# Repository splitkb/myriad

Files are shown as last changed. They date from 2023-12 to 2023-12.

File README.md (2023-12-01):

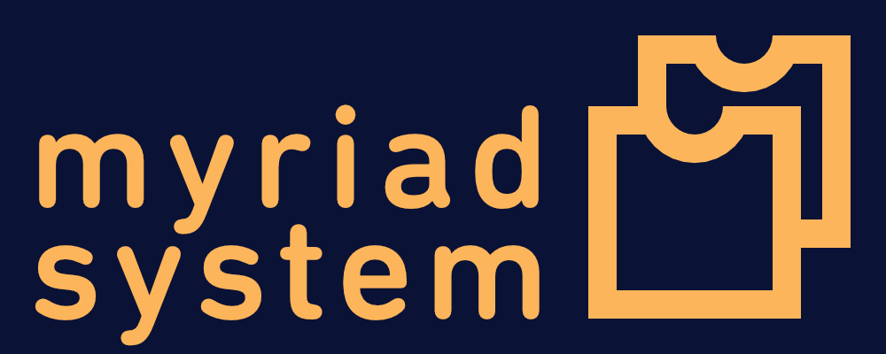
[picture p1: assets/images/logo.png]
Myriad logo


# Myriad

This repository stores the public documentation for the [Myriad System](https://myriad.splitkb.com/). Did you see any mistakes? Feel free to submit a pull request!

## Symbols & footprints
You can find KiCad symbols and footprints [here](assets/kicad/).

## Example projects
You can find some example projects [here](assets/example_projects/).

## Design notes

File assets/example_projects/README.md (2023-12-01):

# Myriad Example projects
Having trouble getting started with your Myriad project? Why not [take a look](https://github.com/splitkb/myriad/archive/refs/heads/main.zip) at these example projects to get an idea of what the end result should look like.

_(Having trouble finding this directory in the ZIP? It's under `assets/kicad`!)_

## protoboard_??x??
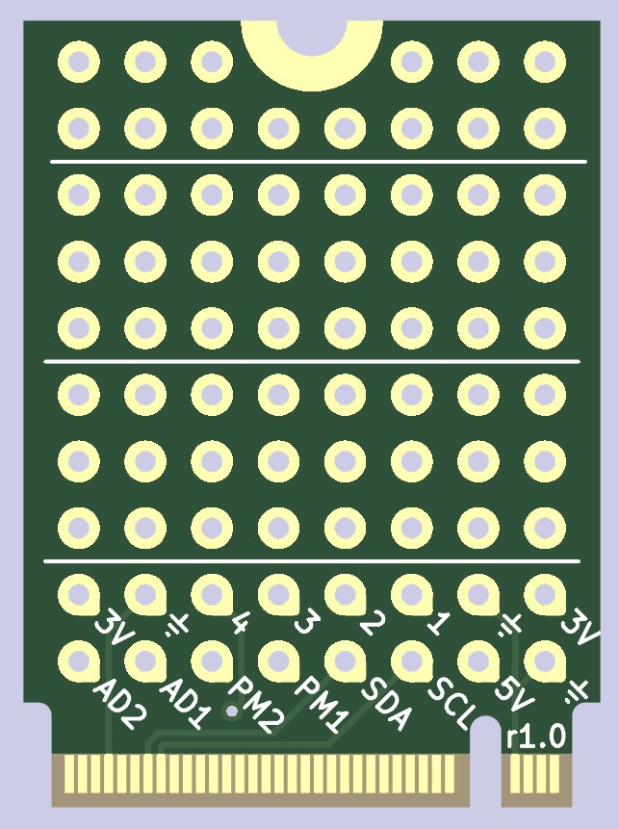
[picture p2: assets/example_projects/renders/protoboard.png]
Proto board


Simple prototyping board. Exposes basic GPIO functionality on the bottom two rows, while providing 3-long strips on the rest of the card. You can use this to build your own simple modules, without having to get a PCB manufactured.

## breakout_22x30
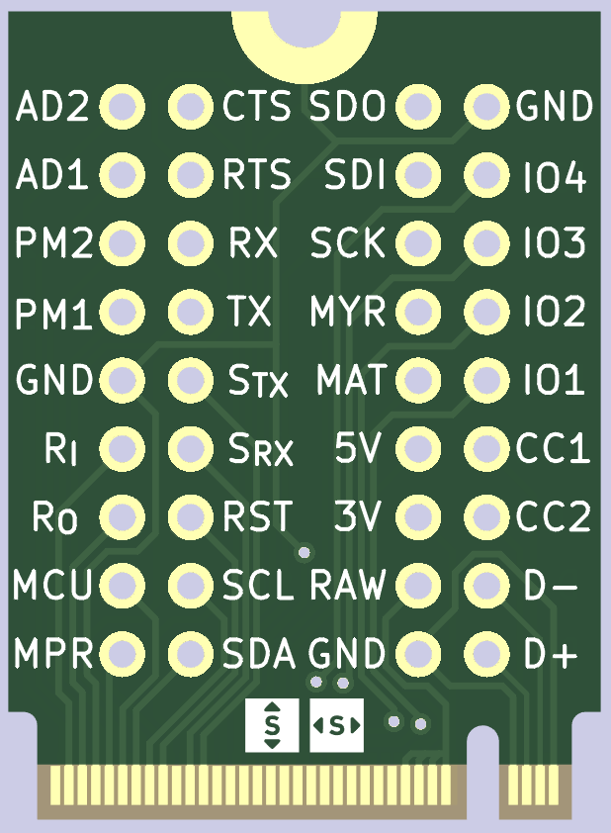
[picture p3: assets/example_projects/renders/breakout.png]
Breakout board


Breakout board. Exposes all currently-available Myriad pins, making it ideal if you want to try connecting external hardware to it.

## Licensing

These files are available for **non-commercial use only**. See [https://myriad.splitkb.com/specification/terms_of_use.html](https://myriad.splitkb.com/specification/terms_of_use.html) for more information.

## More information

Are you looking for the specification, or just want to know more about the Myriad system in general? Visit [https://myriad.splitkb.com/](https://myriad.splitkb.com/)!

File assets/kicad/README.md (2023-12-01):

# Symbols & Footprints

The Myriad system uses a relatively complicated form factor. Especially the edge connector isn't a lot of fun to model.

Luckily, you don't have to! If you're using KiCad, we have created all the required files for you. Just [download this repository](https://github.com/splitkb/myriad/archive/refs/heads/main.zip), add `footprints/` as a footprint library and `symbols/myriad.kycad_sym` as a symbol library, and you're good to go.

_(Having trouble finding this directory in the ZIP? It's under `assets/kicad`!)_

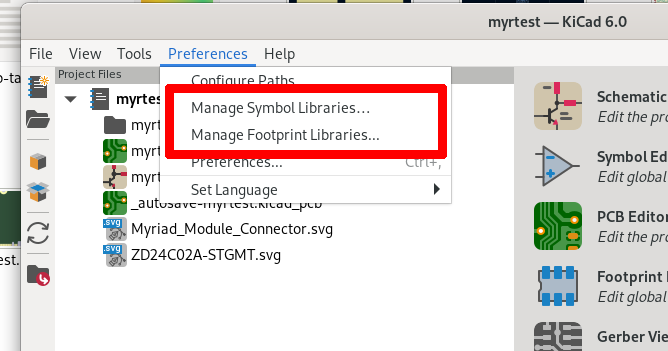
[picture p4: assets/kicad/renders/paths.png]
Kicad paths


## Symbols
### Myriad_Module_Connector
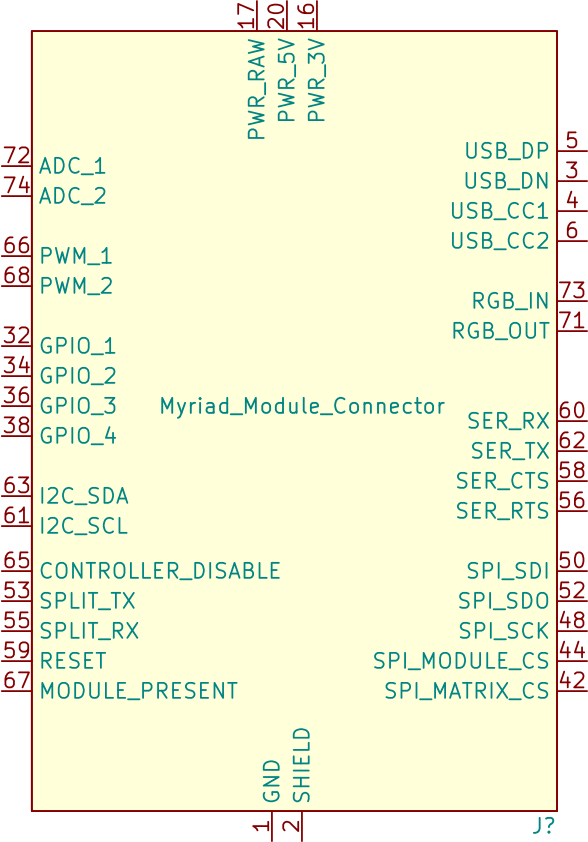
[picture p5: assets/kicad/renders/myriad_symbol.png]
Myriad symbol


This is probably the most important symbol for you: the Myriad module itself. All connections are grouped by purpose.  To figure out how they are supposed to be used, see the [Electrical Specification](https://myriad.splitkb.com/specification/electrical.html) and [Pinout](https://myriad.splitkb.com/specification/pinout.html) for more information. 

They can be paired with the [Myriad_Module_??x??mm](#myriad_module_xmm) and [Myriad_Module_Edge](#myriad_module_edge) footprints.

### Myriad_Keyboard_Connector
It's essentially the same as Myriad_Module_connector, but from the keyboard side. We just flipped the inputs and outputs.

You can use it together with the [Myriad_Socket](#myriad_socket) footprint.

### ZD24C02A-STGMT
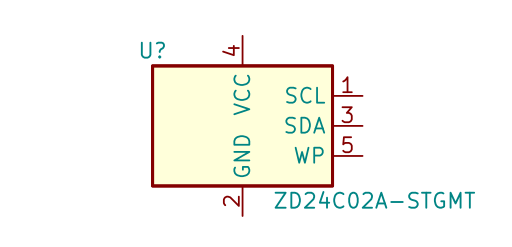
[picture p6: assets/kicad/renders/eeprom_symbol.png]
Zetta symbol


The [Zetta ZD24CxxA](https://www.lcsc.com/product-detail/EEPROM_Zetta-ZD24C08A-STGMT_C2896640.html) is a cheap generic I2C EEPROM which can be used for [card identification](https://myriad.splitkb.com/specification/card_identification/). 

It uses the regular KiCad-provided SOT-23-5 footprint.

Don't feel forced to use this *specific* EEPROM chip - we chose this one for our products because it is cheap and widely available. Did you find a different one? Make sure to compare the [datasheets](https://datasheet.lcsc.com/lcsc/2109141830_Zetta-ZD24C08A-STGMT_C2896640.pdf) for compatibility.

## Footprints
### Myriad_Module_??x??mm
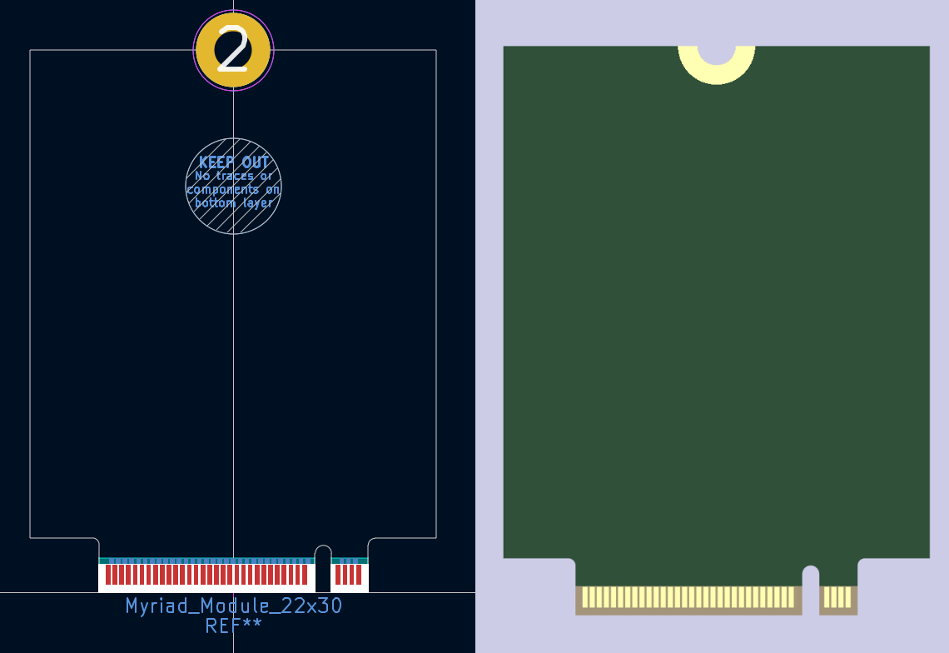
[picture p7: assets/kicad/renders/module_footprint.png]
Module footprint


Premade module footprints including the connector and relevant edge cuts are available for the [common module dimensions](https://myriad.splitkb.com/specification/physical.html). They use the [Myriad_Module_Connector](#myriad_module_connector) symbol.

### Myriad_Module_Edge
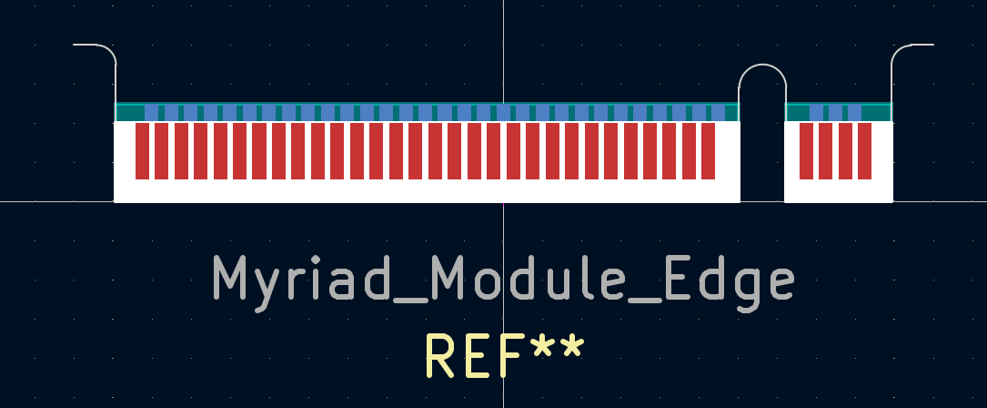
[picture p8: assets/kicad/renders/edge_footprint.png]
Edge footprint


If you're making a module which does not follow the standard sizing edge cuts, we also provide a separate footprint for just the edge connector. This also uses the [Myriad_Module_Connector](#myriad_module_connector) symbol.

Don't forget to add the plated through-hole for screwing it down, and keep the [keepout area](https://myriad.splitkb.com/specification/physical.html#keepout-areas) in mind!

### Myriad_Graphic_{Length/Width}-{S/M/L}
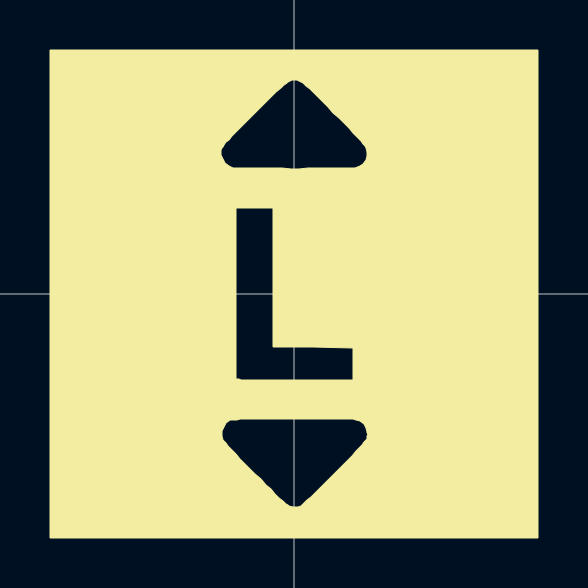
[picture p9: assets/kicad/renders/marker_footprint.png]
Size indicator footprint


These markers can be placed on the module to indicate the standard size they are using. 

### Myriad_Socket
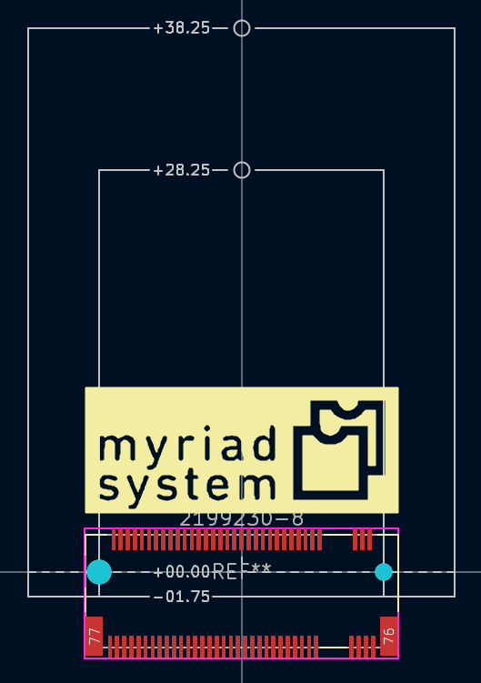
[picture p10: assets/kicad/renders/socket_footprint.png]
Socket footprint


If you're designing a Myriad-compatible keyboard, you can use this footprint to easily get the right dimensions. It is built around the [Myriad_Keyboard_Connector](#myriad_keyboard_connector) footprint and uses the [TE Connectivity 2199230-8](https://octopart.com/2199230-8-te+connectivity-46436158) connector.

It comes with a Myriad logo, outlines of the Small & Medium cards on the `User.Drawings` layer, and offset markers for the `Myriad_Socket_Standoff` footprints.

### Myriad_Socket_Standoff_??mm

Used in combination with the `Myriad_Socket` footprint's `2199230-8`, they mount [Wurth Elektronic 9774025151R](https://octopart.com/9774025151r-wurth+elektronik-59774856) SMD screw standoffs.

Place only the 30mm one for Small cards, and use both 30mm and 40mm for Medium cards and above. If the marker on the `User.Drawings` layer matches up with the +00 line of the Myriad_Socket footprint, they are in the right spot.

## Licensing

See [https://myriad.splitkb.com/specification/terms_of_use.html](https://myriad.splitkb.com/specification/terms_of_use.html).

## More information

Are you looking for the specification, or just want to know more about the Myriad system in general? Visit [https://myriad.splitkb.com/](https://myriad.splitkb.com/)!

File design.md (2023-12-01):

---
layout: default
title: Design your own
nav_order: 4
---

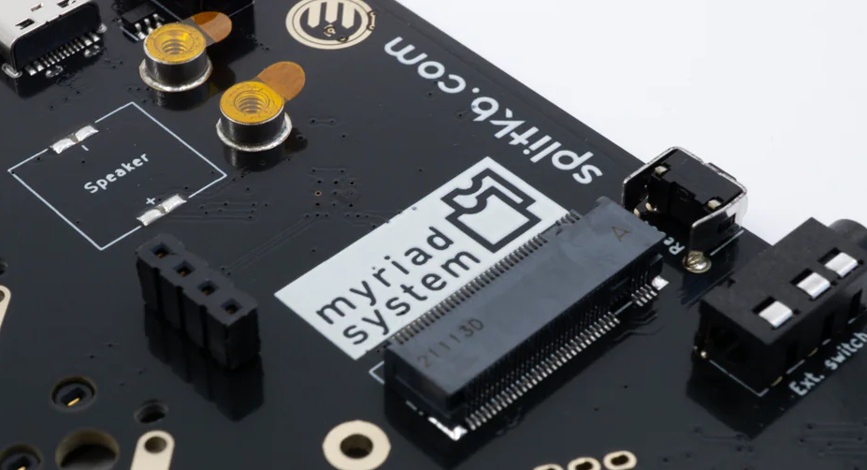
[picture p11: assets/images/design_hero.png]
A Myriad connector


# Specifications
The Myriad system is exhaustively described in [the specifications](specification/).

# Symbols & Footprints
In order to save you some time, we have already created the necessary KiCad footprints and symbols for you. You can find them [here](https://github.com/splitkb/myriad/tree/main/assets/kicad).

# Example projects
Prefer looking at ready-made cards to get a feel of it? Why not take a look at [these](https://github.com/splitkb/myriad/tree/main/assets/example_projects)?

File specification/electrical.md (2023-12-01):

---
layout: default
title: Electrical Specifications
parent: Specification
nav_order: 2
---

# Electrical Specification
Unless stated otherwise, all IO pins use 3.3V.

IO pins are driven from a microcontroller, so expect them to sink/source about 10mA. You can power a LED from them, but don't expect them to drive a servo.

# Power
The keyboard provides three potential power sources to the card.

## 3V3
This is the main supply for digital logic. It is always available. The keyboard has to convert the 5V provided from USB into 3V3, so anything drawing very large amounts of current should use the 5V rail instead.

Keyboards are expected to supply about 500mA on the 3V3 rail.

## 5V
Used to supply power-hungry components, like RGB LEDs. It is available on both sides of a split keyboard.

The 5V supply must be protected by an overcurrent fuse on the keyboard. As with any USB device, expect it to supply about 500mA.

{: .note }
Controller modules are not required to supply 5V to the keyboard: the keyboard is required to operate with only 3V3.

## Raw
Direct power from the USB connector, used for things like battery charging.

A module can **passively** measure the voltage on the two [CC pins](pinout.html#usb) to determine roughly how much power can be drawn. The highest voltage determines the maximum current allowed:

|Voltage  |Allowed current|
|---|---|
|< 0.2V |None, USB disconnected |
|0.2V - 0.66V |500 mA |
|0.66V - 1.23V|1500 mA |
|> 1.23V |2000 mA |

A module may **never** draw more than 2000 mA, as that is the absolute limit of the connector.

{: .warning }
USB PD communication is **explicitly forbidden**. The module may **only** measure the voltage present on the CC pins.

{: .note }
On split keyboards, raw power is only available on the primary half.

# Ground
Ground pins have been distributed along the connector. Connect ground pins close to high-speed connections for better signal integrity.

All ground pins are connected on the keyboard, feel free to leave some disconnected when not needed.

# Reserved pins
For compatibility with future revisions, all reserved pins **must** be left floating.

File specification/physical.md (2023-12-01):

---
layout: default
title: Physical Dimensions
parent: Specification
nav_order: 1
---
# Physical Dimensions

Myriad cards use the M.2 form factor, also known as "NGFF". It is commonly used by NVMe SSDs and Wifi cards. This means that the [M.2 specification](/assets/pdf/m2_spec.pdf) serves as the basis for the Myriad specification.

This page describes the physical dimensions required to create a Myriad-compatible card. You can also use one of our [footprints](/design.html#resources) if you want to save yourself some trouble.

{: .warning }
Make sure you order your cards with a thickness of 0.80mm!

## Keying
Myriad cards, like all other M.2 cards, have a physical "notch" preventing the insertion of incompatible cards. Myriad cards use **Key A**. This means pins 8-15 are missing. Pins 24-31 (Key E) are [kept reserved](electrical.html#reserved-pins) for potential future use.

## Card edge
In order to allow insertion, the card must be 0.80mm (± 0.08mm) thick. ENIG finish is strongly recommended for durability. Contrary to the M.2 specification, a card edge bevel is not required.

For card edge pads and cutout dimensions, please see Figure 16 through 18 of the [M.2 specification](/assets/pdf/m2_spec.pdf) (pages 39-41). We recommend using our pre-existing [footprints](/design.html#resources) to avoid having to manually copy this.

## Card dimensions
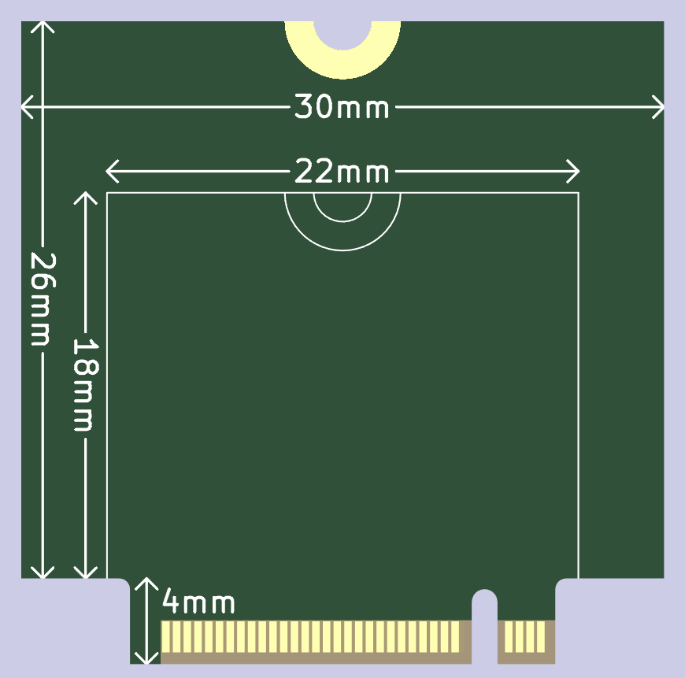
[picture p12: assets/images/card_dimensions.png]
Card dimensions


We define a set of standard card sizes to make it easier to determine whether a card will fit a specific keyboard.

The following sizes are defined:

| *Size codes* | **22mm wide** | **30mm wide** | **> 30mm wide** |
| **22mm tall** | SS | SM | SL |
| **30mm tall** | MS | MM | ML |
| **> 30mm tall** | LS | LM | LL |

Cards which are Small or Medium in either width or height will always fit into a keyboard matching that size. Cards which have one or more Large dimensions are *not* guaranteed to fit - the card maker should publish exact dimensions and compatibility with the most common keyboards.

If physically possible, the size code should be marked LINK on the card itself.

{: .note }
Card height includes the 4mm needed for the connector.

## Standoff
The card is secured using a standoff and regular M2.5 screw. If the keyboard supports cards of length S (22mm) or larger, a standoff will be present at 22mm. If the keyboard supports cards of length M (30mm) or larger, a second standoff will be present at 30mm.

The card must have a circular cutout at either y=22mm or y=30mm with a diameter of 2.7mm (radius 1.35mm), surrounded by a plated pad with a diameter of 5.4mm (radius 2.7mm). On most cards, this will result in a half-circle due to the card's length.

## Keepout areas
In order to avoid interfering with the socket, do not place any components:
- Within 4.0mm of the connector card edge on the frontside.
- Within 5.2mm of the connector card edge on the backside.

Within a 3.5mm radius of (x=0mm, y=30mm) on the backside, do not place any components n order to avoid interfering with the 30mm standoff. Placing signal or power traces in this area is **strongly** discouraged, but a ground plane is fine.

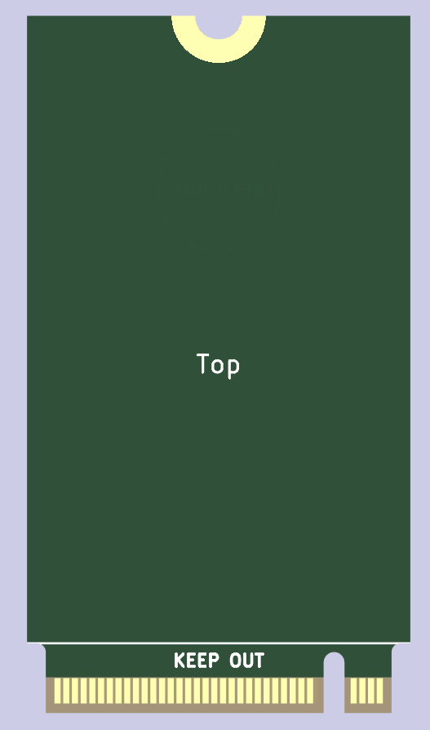
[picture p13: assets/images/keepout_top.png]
Keepout areas front

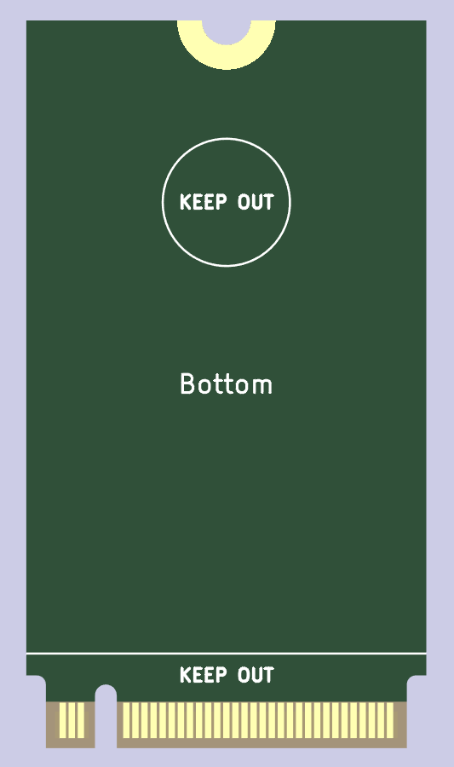
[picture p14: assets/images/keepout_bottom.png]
Keepout areas back


## Vertical spacing
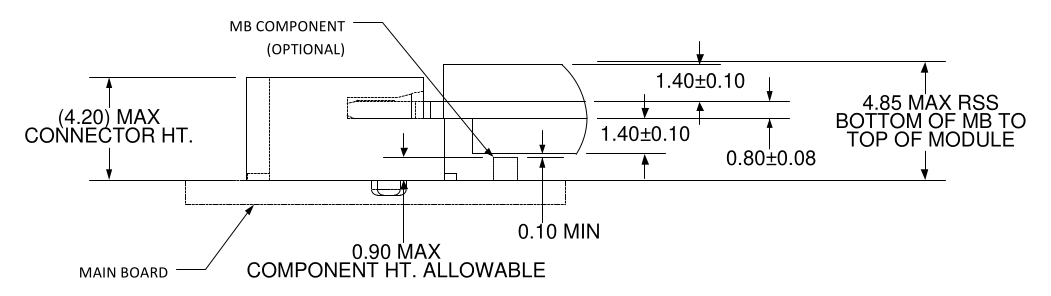
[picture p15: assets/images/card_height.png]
Card height


Components on the **bottom** of the cards must be at most **1.40mm** tall, leaving 0.90mm for components placed on the keyboard. Component height on the **top** is unrestricted, provided they remain within the card boundaries.

{: .note }
Keyboards may use connectors shorter than 4.20mm - but that makes finding standoffs a lot trickier.

## Mounting Hardware
If you are designing your own keyboard, we recommend the TE Connectivity [2199230-8](https://octopart.com/2199230-8-te+connectivity-46436158) ([datasheet](/assets/pdf/socket_datasheet.pdf)) connector  and Wurth Elektronik [9774025151R](https://octopart.com/9774025151r-wurth+elektronik-59774856) ([datasheet](/assets/pdf/standoff_datasheet.pdf)) standoffs, but any compatible ones will do.

Footprints are provided in our [repository](/design.html#resources).

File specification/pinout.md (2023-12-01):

---
layout: default
title: Pinout
parent: Specification
nav_order: 3
---

# Myriad Pinout
This document serves as a reference when creating Myriad cards. You don't need to make your own symbols - we already did that [for you](design.html#resources)

- *Odd pins are on the top, even pins are on the bottom*
- *Pins marked with a 🚧 may only be used by [controller cards](#controller-cards)*
- *Unless explicitly stated otherwise, all IO pins use 3.3V.*

|\#|Group|Name|Description|
|---|---|-----|----|---|
|01|[Power](electrical.html#power)|GND|Ground|
|02|[Power](electrical.html#power)|Shield|Case shield|
|03|[USB](#usb)|D- [🚧](#controller-cards)|USB data|
|04|[USB](#usb)|CC 1|USB current sense|
|05|[USB](#usb)|D+ [🚧](#controller-cards)|USB data|
|06|[USB](#usb)|CC 2|USB current sense|
|07|[Power](electrical.html#power)|GND|Ground|
|08-15|*(Unused)*|*Key A*|Board cutout|
|16|[Power](electrical.html#power)|3V3||
|17|[Power](electrical.html#power)|Raw||
|18|[Power](electrical.html#power)|3V3||
|19|[Power](electrical.html#power)|Raw||
|20|[Power](electrical.html#power)|5V||
|21|[Power](electrical.html#power)|Raw||
|22|[Power](electrical.html#power)|5V||
|23|[Power](electrical.html#power)|Raw||
|24-31|*(Unused)*|*(Reserved)*|[Leave disconnected](electrical.html#reserved-pins)|
|32|[GPIO](#gpio)|GPIO 1|General-purpose IO|
|33|*(Unused)*|*(Reserved)*|[Leave disconnected](electrical.html#reserved-pins)|
|34|[GPIO](#gpio)|GPIO 2|General-purpose IO|
|35|*(Unused)*|*(Reserved)*|[Leave disconnected](electrical.html#reserved-pins)|
|36|[GPIO](#gpio)|GPIO 3|General-purpose IO|
|37|*(Unused)*|*(Reserved)*|[Leave disconnected](electrical.html#reserved-pins)|
|38|[GPIO](#gpio)|GPIO 4|General-purpose IO|
|39|*(Unused)*|*(Reserved)*|[Leave disconnected](electrical.html#reserved-pins)|
|40|[Power](electrical.html#power)|GND|Ground|
|41|*(Unused)*|*(Reserved)*|[Leave disconnected](electrical.html#reserved-pins)|
|42|[SPI](#spi)|[Matrix CS](#matrix-data) [🚧](#controller-cards)|Chip Select, keyboard matrix|
|43|*(Unused)*|*(Reserved)*|[Leave disconnected](electrical.html#reserved-pins)|
|44|[SPI](#spi)|Myriad CS|Chip Select, Myriad module|
|45|*(Unused)*|*(Reserved)*|[Leave disconnected](electrical.html#reserved-pins)|
|46|[Power](electrical.html#power)|GND|Ground|
|47|*(Unused)*|*(Reserved)*|[Leave disconnected](electrical.html#reserved-pins)|
|48|[SPI](#spi)|SCK|Clock|
|49|*(Unused)*|*(Reserved)*|[Leave disconnected](electrical.html#reserved-pins)|
|50|[SPI](#spi)|SDI|Data, Module to Keyboard|
|51|*(Unused)*|*(Reserved)*|[Leave disconnected](electrical.html#reserved-pins)|
|52|[SPI](#spi)|SDO|Data, Keyboard to Module|
|53|Misc|[Split Comm.](#split-communication) TX [🚧](#controller-cards)|Serial link between halves, transmit|
|54|[Power](electrical.html#power)|GND|Ground|
|55|Misc|[Split Comm.](#split-communication) RX [🚧](#controller-cards)|Serial link between halves, receive|
|56|[Serial](#serial)|RTS|Request-To-Send, Keyboard to Module|
|57|[Power](electrical.html#power)|GND|Ground|
|58|[Serial](#serial)|CTS|Clear-To-Send, Module to Keyboard|
|59|Misc|[Reset](#reset)|Reset keyboard & module|
|60|[Serial](#serial)|RX|Data, Module to Keyboard|
|61|[I2C](#i2c)|SCL|Clock|
|62|[Serial](#serial)|TX|Data, Keyboard to Module|
|63|[I2C](#i2c)|SDA|Data|
|64|[Power](electrical.html#power)|GND|Ground|
|65|Misc|[Controller Disable](#controller-disable) [🚧](#controller-cards)|Keyboard controller override|
|66|[PWM](#pwm)|PWM 1|Pulse-width modulation|
|67|Misc|[Module Present](#module-presence)|Myriad module inserted|
|68|[PWM](#pwm)|PWM 2|Pulse-width modulation|
|69|[Power](electrical.html#power)|GND|Ground|
|70|[Power](electrical.html#power)|GND|Ground|
|71|RGB|[RGB Out](#rgb)|RGB data, Keyboard to Module|
|72|[ADC](#adc)|ADC 1|Analog input|
|73|RGB|[RGB In](#rgb-1) [🚧](#controller-cards)|RGB data, Module to Keyboard|
|74|[ADC](#adc)|ADC 2|Analog input|
|75|*(Unused)*|*(Reserved)*|[Leave disconnected](electrical.html#reserved-pins)|

# Basic IO

### Reset
The Myriad module and keyboard share an active-low Reset signal. This can be used both to have a press of the on-keyboard reset button reset hardware placed on the Myriad card, or to have an additional reset button for the keyboard on the Myriad card. The keyboard will provide a pull-up.

### Module Presence
All [identifiable](card_identification/) Myriad cards **must** short Module Presence to Ground to indicate that a card has been inserted. Leave it floating for cards which cannot be automatically identified.

{: .note }
Automatic identification doesn't make sense for all cards. For example, a breakout board does not have fixed functionality, so it should not have an EEPROM chip and the Module Presence pin should be left floating.

### Signals

|\#| Pin |
|--|-----|
|59| Reset |
|67| Module presence |

## GPIO
GPIO pins can be used for general low-speed IO such as reading a push button or controlling a LED. They can be used for both input and output.

GPIO pins have support for internal pullup resistors, but internal pulldown resistors are not guaranteed. If you need pulldown resistors, you have to add them yourself.

### Signals

|\#| Pin |
|--|-----|
|32| GPIO 1 |
|34| GPIO 2 |
|36| GPIO 3 |
|38| GPIO 4 |

## PWM
The two PWM pins can be used to output analog-like signals, such as lighting with varying brightness or a speaker.

They can double as additional GPIO outputs if needed.

### Signals

|\#| Pin |
|--|-----|
|66| PWM 1 |
|68| PWM 2 |

## ADC
The two ADC pins can be used to read analog signals, for example from potentiometers or joysticks.

They can double as additional GPIO inputs if needed.

### Signals

|\#| Pin |
|--|-----|
|72| ADC 1 |
|74| ADC 2 |

## RGB
The Myriad module may have one or more WS2812B-compatible RGB LEDs. It is chained through similar LEDs on the keyboard itself, if any.

{: .warning }
Because the RGB data is provided by the previous LED in the chain, this is a **5V signal**.

### Signals

|\#| Pin |
|--|-----|
|71| RGB Out |

# Advanced IO
## SPI
[SPI](https://en.wikipedia.org/wiki/Serial_Peripheral_Interface) is the primary high-speed data bus for Myriad. It can transfer data at a rate of over 1Mbps, which should be sufficient for even the most demanding accessories.

### Implementation Notes

- **The module may only interact with SDI / SDO when CS is LOW**. When CS is HIGH, all signals coming from the keyboard should be ignored and all signals going back to the keyboard should be left in a [Hi-Z](https://en.wikipedia.org/wiki/High_impedance#Digital_electronics) state as hardware on the keyboard itself might be using the SPI bus.
- The keyboard will provide a pullup on CS.
- Phasing, polarity, and clock speed are not specified.

{: .warning }
SPI pins should **not** be reused as additional GPIO.

### Signals

|\#| Pin | From | To |
|-|-----|---|----|
|44| CS / SS | Keyboard | Module |
|48| SCK / SCLK | Keyboard | Module |
|50| SDI / MISO | Module | Keyboard |
|52| SDO / MOSI | Keyboard | Module |

## I²C
[I²C](https://en.wikipedia.org/wiki/I%C2%B2C) is the primary low-speed data bus for Myriad. It can transfer data at a rate of 100kbps, which is sufficient for undemanding applications.

The I²C bus is primarily used for [card identification](card_identification/), although the Myriad module is free to use it for other purposes.

### Implementation Notes
- **Address range `1010 000X` - `1010 111X` is reserved**, where X is the R/W bit.
- Speed is limited to 100kbps.
- The keyboard may add additional devices to the I²C bus.

{: .warning }
I²C pins should **not** be reused as additional GPIO.

### Signals

|\#| Pin |
|--|-----|
|61| Clock |
|63| Data |

## Serial
A full serial bus is present to simplify interaction with high-speed hardware which doesn't support SPI.

They can double as additional GPIO inputs if needed, but signal direction should be respected.

### Implementation Notes
- Baud rate is not specified.
- Use of RTS/CTS for flow control is optional.

### Signals

|\#| Pin | From | To |
|-|-----|---|----|
|56| RTS | Keyboard | Module |
|58| CTS | Module | Keyboard |
|60| RX | Module | Keyboard |
|62| TX | Keyboard | Module |

# Controller Cards
A "Controller Card" is a Myriad module which takes over the tasks of the on-keyboard microcontroller. Adding a Controller Card essentially turns the entire board into an io expander.

Several lines on the Myriad connector are reserved for use by Controller Cards, as they will be used by the keyboard's microcontroller when regular cards are used.

## Controller Disable
To indicate the presence of a controller card, the card must short pin 65 to Ground. If a keyboard microcontroller detects this short on bootup, it immediately enters a low-power sleep mode and does not interact with the keyboard hardware.

Regular cards must leave this pin floating.

### Signals

|\#| Pin |
|--|-----|
|65| Controller Disable |

## Power
### Wired
Controller cards intended for wired operation should use the regular 3V3 and 5V rails to source their power from the keyboard.

### Wireless
Controller cards intended for wireless operation must instead *provide* power to the keyboard. The card is **required** to provide 3V3 to the keyboard, and the keyboard shall provide basic functionality with only 3V3 provided.

Additionally, the card *may* provide 5V. The keyboard may attach high-power functionality (such as RGB LEDs) directly to the 5V bus - they will not be available with cards which only provide 3V3.

The card may use the RAW pins to source battery charging powers - see the [Power section](electrical.html#power). 

{: .note }
Wireless cards providing power to the keyboard should take into account the RAW->5V->3V3 power supply already present on the keyboard.

## Matrix Data
The controller card can read the current state of the key matrix via the SPI bus. If the keyboard has encoders, their state will also be included. Most keyboards will implement this using cheap shift registers, but other implementations are allowed.

The matrix data is read using the same pins as regular SPI, but their direction is reversed. Note that it uses a **different** Chip Select pin, though!

### Signals

|\#| Pin | From | To |
|-|-----|---|----|
|**42**| CS / SS | Keyboard | Module |
|48| SCK / SCLK | Module | Keyboard |
|50| SDI / MISO | Keyboard | Module |
|52| SDO / MOSI | Module | Keyboard |

## Split Communication
Split keyboards consists of two halves, with a communications link between them. When a controller card is in use, it may use this link to communicate with its partner inserted into the other half.

### Implementation Notes
- The communications link is full-duplex. You **must** use separate pins for transmit and receive - using a single pin for both does not work as the keyboard may be using a level converter. 

### Signal Directions

|\#| Pin | From | To |
|-|-----|---|----|
|53| TX | This side | Other side |
|55| RX | Other side | This side |

## RGB
The keyboard may have one or more chained WS2812B-compatible RGB LEDs which can be driven by a controller card.

{: .note }
Despite it feeding a WS2812B LED, it is a 3V3 signal. Any level conversion is left to the keyboard.

### Signals

|\#| Pin |
|--|-----|
|73| RGB In |

## USB
Controller cards may use the USB bus to communicate with a host computer. Keep in mind that signal quality is likely going to be relatively poor due to routing limitations: Full-speed communication (12Mbps) will work, but High-speed (480Mbps) is not guaranteed.

The USB connector also provides the CC signals needed to sense the [absolute power limit](electrical.html#raw).

### Signals

|\#| Pin |
|--|-----|
|03| D- |
|04| CC 1 |
|05| D+ |
|06| CC 2 |

# Known Pin Mappings
The table below describes the physical connectivity between the microcontroller and the Myriad connector of some keyboards implementing Myriad.

|Myriad \#|Name|[Elora](/products.html#elora)|
|---|----|---|
|32|GPIO 1|GP4|
|34|GPIO 2|GP5|
|36|GPIO 3|GP6|
|38|GPIO 4|GP8|
|44|SPI Myr. CS|GP9|
|48|SPI SCK|GP10|
|50|SPI SDI|GP12|
|52|SPI SDO|GP11|
|56|Ser. RTS|GP19|
|58|Ser. CTS|GP18|
|60|Ser. RX|GP17|
|61|I2C SCL|GP1|
|62|Ser. TX|GP16|
|63|I2C SDA|GP0|
|65|Cont. Disable|GP2|
|66|PWM 1|GP23|
|67|Mod. Present|GP3|
|68|PWM 2|GP24|
|71|RGB Out|GP15|
|72|ADC 1|GP26|
|74|ADC 2|GP27|

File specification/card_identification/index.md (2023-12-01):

---
layout: default
title: Card Identification
parent: Specification
has_children: true
nav_order: 4
---

# Card Identification
Myriad uses EEPROM chips placed on the card to allow identification of the card inserted. This allows the keyboard to automatically configure the card for use, allowing for a seamless no-code experience.

{: .note }
Automatic identification doesn't make sense for all cards. For example, a breakout board does not have fixed functionality, so it should not have an EEPROM chip and [pin 67](../pinout.html#module-presence) should be left floating.

If you want to comfirm whether you are understanding the specification correctly, why not try decoding one of the [example records](examples.html)?

# EEPROM Selection and Addressing
The Myriad ecosystem use standard 2kb-16kb I²C EEPROM chips, such as the [Zetta ZD24C16A](https://datasheet.lcsc.com/lcsc/2109141830_Zetta-ZD24C08A-STGMT_C2896640.pdf). They use the address range `1010 000X` - `1010 111X`.

The EEPROM chips use 2kb pages, with the 3 LSBs of the device address used for page selection. If no page selection is possible, the relevant bit is set to 0. This means a 2kb EEPROM chip will *always* use address `1010 000X`, but a 16kb chip will use the entire `1010 000X` - `1010 111X` range.

Write protection is allowed, but not mandatory.

# Endianness

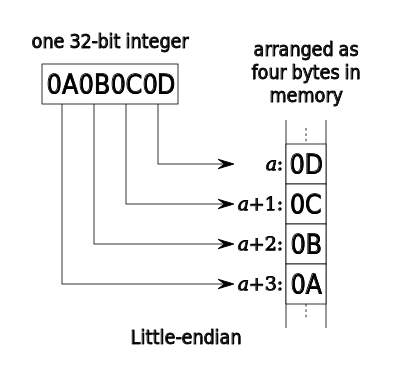
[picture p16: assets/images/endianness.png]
Little endian byte ordering
  
*[CC BY-SA: Wikipedia, User:Aeroid](https://en.wikipedia.org/wiki/Endianness#/media/File:32bit-Endianess.svg)*

All data is stored little-endian. This means that the uint16 `33825` (`0x8421`) is stored as `[0x21, 0x84]`. This aligns with how most modern CPU & MCU architectures store their data internally, making it trivial to cast data to a struct.

# Header

| Length | Format | Description |
|---|---|---|
| 3 | 0x`4D 59 52` | [Magic number](https://en.wikipedia.org/wiki/Magic_number_(programming)), ASCII characters `MYR`.
| 3 | uint8 `major`, uint8 `minor`, uint8 `patch` | [Version number](versioning.html), currently `01 00 00`.
| 4 | uint32 | Payload Checksum. [Adler-32](https://en.wikipedia.org/wiki/Adler-32) checksum of the entire payload.
| 2 | uint16 | Payload length in bytes.
| n | - | Payload, consists of one or more [entries](#payload-entries).

# Payload entries
Payload entries follow the following format:

| Length | Format | Description |
|---|---|---|
| 1 | uint8 | Entry type identifier.
| 1 | uint8 | Data length in bytes.
| n | - | Data, format depends on entry type.

Note that this allows the reader to trivially skip unsupported entry types. Payload entries may appear in any order. Some payload entry types may be repeated.

# Payload Entry Types
Note that new entry types may be added from time to time in order to support additional functionality.

## Metadata
### Card Identifier
*Mandatory: No. Repeatable: No. Since: 1.0.0.*

{: .warning }
This entry **must** be present!

| Length | Format | Description |
|---|---|---|
| 1 | `0x01` | Entry type identifier.
| 1 | `0x05` | Data length in bytes.
| 2 | uint16 | [Vendor ID](vendor_ids.html).
| 2 | uint16 | Product ID.
| 1 | uint8 | Product revision.

Assignment of Product ID and revision is left to each individual vendor. However, the combination of Product ID and revision **must** uniquely identify a distinct product. If two products have the same ID and revision, they must be fully interchangeable both electronically and from software.

### Vendor Name
*Mandatory: No. Repeatable: No. Since: 1.0.0.*

| Length | Format | Description |
|---|---|---|
| 1 | `0x02` | Entry type identifier.
| 1 | `n` | Data length in bytes.
| n | utf-8 | Vendor Name String.

A human-readable string identifying the vendor. The string is *not* null-terminated.

### Product Name
*Mandatory: No. Repeatable: No. Since: 1.0.0.*

| Length | Format | Description |
|---|---|---|
| 1 | `0x03` | Entry type identifier.
| 1 | `n` | Data length in bytes.
| n | utf-8 | Product Name String.

A human-readable string identifying the product. The string is *not* null-terminated.

### Product URL
*Mandatory: No. Repeatable: No. Since: 1.0.0.*

| Length | Format | Description |
|---|---|---|
| 1 | `0x04` | Entry type identifier.
| 1 | `n` | Data length in bytes.
| n | utf-8 | Product URL String.

A human-readable string representing a URL pointing to a website with more information about the product. The string is *not* null-terminated.

## General IO
### Button / Switch
*Mandatory: No. Repeatable: Yes. Since: 1.0.0.*

| Length | Format | Description |
|---|---|---|
| 1 | `0x10` | Entry type identifier.
| 1 | `0x02` | Data length in bytes.
| 1 | uint8 | [Pin number](/specificatio/pinout.html) on the connector.
| 1 | uint8 | Configuration bit field

The configuration bit field uses the following format:

| Bit | Meaning |
|---|---|
| 0 (LSB) | 0: Momentary, 1: Toggle
| 1 | 0: No pullup needed, 1: Pullup needed
| 2 | 0: Do not invert (0=off, 1=on), 1: Invert value (0=on, 1=off)
| 3 | *Reserved, set to 0*
| 4 | *Reserved, set to 0*
| 5 | *Reserved, set to 0*
| 6 | *Reserved, set to 0*
| 7 (MSB) | *Reserved, set to 0*

Describes a simple push button or switch, which provides either a high or low value to a gpio pin.

### Rotary Encoder
*Mandatory: No. Repeatable: Yes. Since: 1.0.0.*

| Length | Format | Description |
|---|---|---|
| 1 | `0x11` | Entry type identifier.
| 1 | `0x03` | Data length in bytes.
| 1 | uint8 | [Pin number](/specification/pinout.html) on the connector, contact A.
| 1 | uint8 | [Pin number](/specification/pinout.html) on the connector, contact B.
| 1 | uint8 | Configuration bit field

The configuration bit field uses the following format:

| Bit | Meaning |
|---|---|
| 0 (LSB) | 0: Smooth, 1: Tactile
| 1 | 0: No pullups needed, 1: Pullups needed
| 2-4 | Encoder resolution, 0: undefined, 1-7: resolution
| 5-7 (MSB) | Encoder default position

Describes a rotary encoder, like the EC11.

### 2D Joystick
*Mandatory: No. Repeatable: Yes. Since: 1.0.0.*

| Length | Format | Description |
|---|---|---|
| 1 | `0x12` | Entry type identifier.
| 1 | `0x03` | Data length in bytes.
| 1 | uint8 | [Pin number](/specification/pinout.html) on the connector, X axis.
| 1 | uint8 | [Pin number](/specification/pinout.html) on the connector, Y axis.
| 1 | uint8 | Configuration bit field

The configuration bit field uses the following format:

| Bit | Meaning |
|---|---|
| 0 (LSB) | 0: Do not invert X, 1: Invert X axis.
| 1 | 0: Do not invert Y, 1: Invert Y axis.
| 2 | *Reserved, set to 0*
| 3 | *Reserved, set to 0*
| 4 | *Reserved, set to 0*
| 5 | *Reserved, set to 0*
| 6 | *Reserved, set to 0*
| 7 (MSB) | *Reserved, set to 0*

Describes an analog joystick.

### Addressable RGB LEDs
*Mandatory: No. Repeatable: No. Since: 1.0.0.*

| Length | Format | Description |
|---|---|---|
| 1 | `0x12` | Entry type identifier.
| 1 | `0x03` | Data length in bytes.
| 1 | uint8 | LED count.
| 1 | uint8 | Power usage per LED, black (`00 00 00`), in 0.1 mA.
| 1 | uint8 | Power usage per LED, white (`FF FF FF`), in 1 mA.

Describes a set of WS2812B-compatible RGB LEDs, connected to the dedicated [RGB Out](/specification/pinout.html#rgb) pin.

Power usage values are used to dynamically adjust maximum brightness in order to stay within keyboard power limits. If unknown, use `0`.

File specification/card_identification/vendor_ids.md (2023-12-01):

---
layout: default
title: Vendor IDs
parent: Card Identification
grand_parent: Specification
nav_order: 2
---

# Vendor IDs

Vendor IDs allow each designer to give their cards a unique identifier without risking an accidental ID collision.

If you wish to make your Myriad products publicly available, you should [register a Vendor ID](https://github.com/splitkb/myriad/issues/new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) - it's free!

{: .note }
You don't need to register a Vendor ID for personal use - you can just use the reserved VID `FFFF` for your prototypes or personal projects.

| Value | Name | URL |
|---|---|-----|
| `0000` | *Reserved* | *Reserved for future use* |
| `0001` | splitkb.com | [https://splitkb.com](https://splitkb.com) |
| `FFFF` | *Reserved* | Used for DIY cards which are not commercially available |

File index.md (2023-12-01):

---
title: Introduction
layout: home
nav_order: 1
---

Myriad logo

# Myriad: Keyboards Made Modular
This is the documentation for the Myriad System, introduced by [splitkb.com](https://splitkb.com). You can use this documentation to get started designing your own Myriad card.

## Cards purchased at splitkb.com
Looking for documentation on how to use your existing Myriad card? You can find Myriad card documentation at [docs.splitkb.com](https://docs.splitkb.com) for all cards purchased from splitkb.com.

## Cards purchased from third parties
Did you get a Myriad card from a third party? Great, it is always nice to see the ecosystem grow! However, that also means they were not designed by us, so we cannot provide documentation or usage instructions for them. Please contact the seller if you have questions about them.

Asking in the [#myriad channel over on the splitkb.com Discord server](https://splitkb.com/discord) is of course allowed, but we can't make any promises.

## Designing your own card
Looking to get started designing your own Myriad card or Myriad host? Read the [Terms of Use](specification/terms_of_use.md) first. In it, you'll find that you can freely modify and even sell Myriad cards commercially, but Myriad host boards cannot be sold commercially. For more licensing information, please contact [splitkb.com support](mailto:support@splitkb.com).

Once you're familiar with the license, you can get started with the design. 
Read up on the resources to ensure you and others will be able to use your Myriad card, determine the right size for your card, and then [dive into the specs](specification/)!

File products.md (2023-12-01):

---
layout: default
title: Myriad Products
nav_order: 3
---

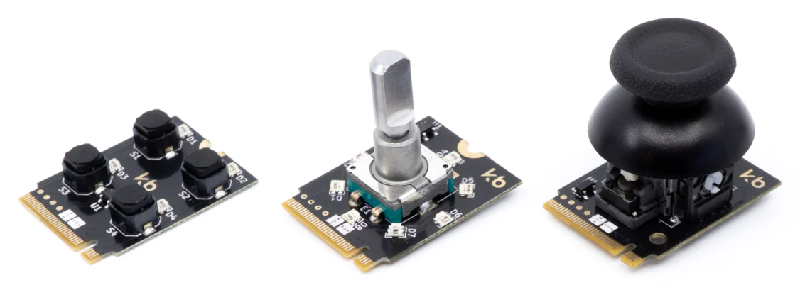
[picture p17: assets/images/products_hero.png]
Some Myriad modules


# Available Myriad Products

The following products are already using the Myriad standard:

## Keyboards

### **splitkb.com**

*Available at:* [https://splitkb.com/](https://splitkb.com/)

### Elora
_ID: `0001:8001`_

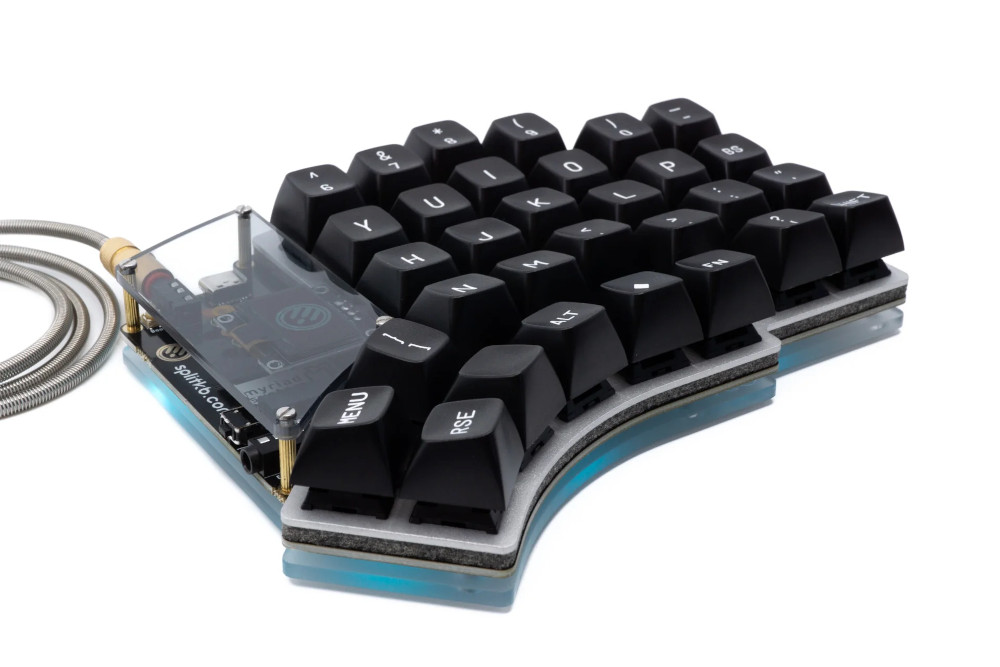
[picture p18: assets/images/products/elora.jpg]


## Cards

### **splitkb.com**

*Available at:* [https://splitkb.com/](https://splitkb.com/)

### Encoder
_ID: `0001:0001`_

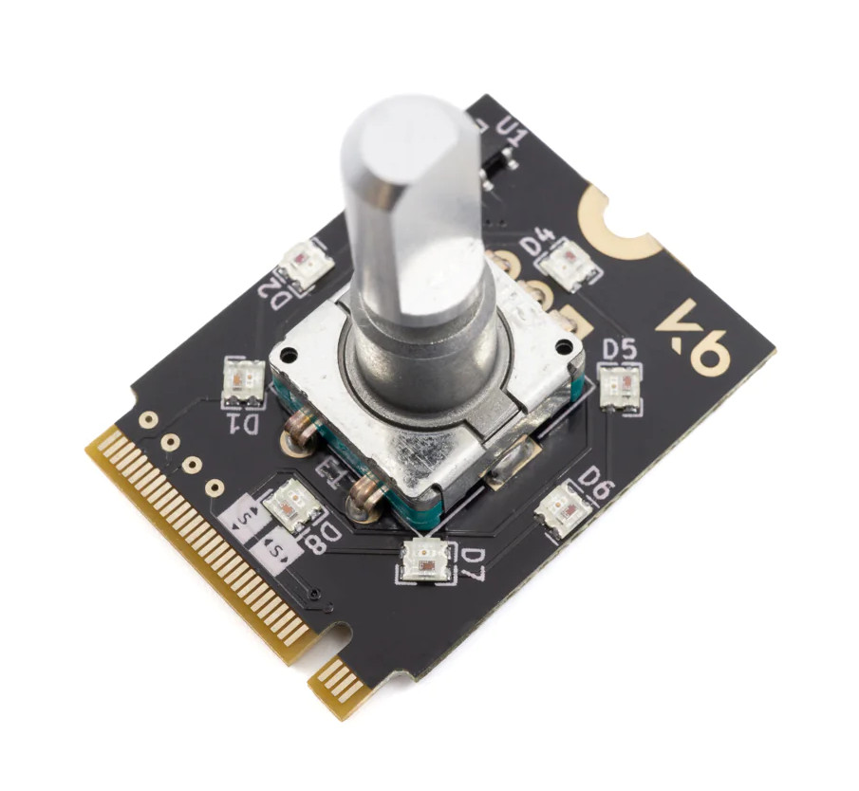
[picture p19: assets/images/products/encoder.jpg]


### Joystick
_ID: `0001:0002`_

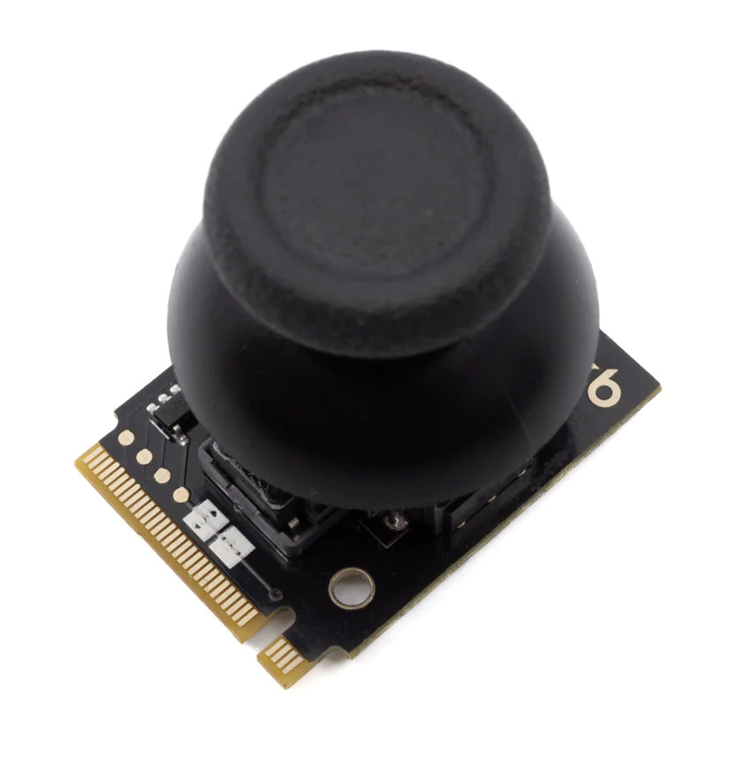
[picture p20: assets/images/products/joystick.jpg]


### Macropad
_ID: `0001:0003`_

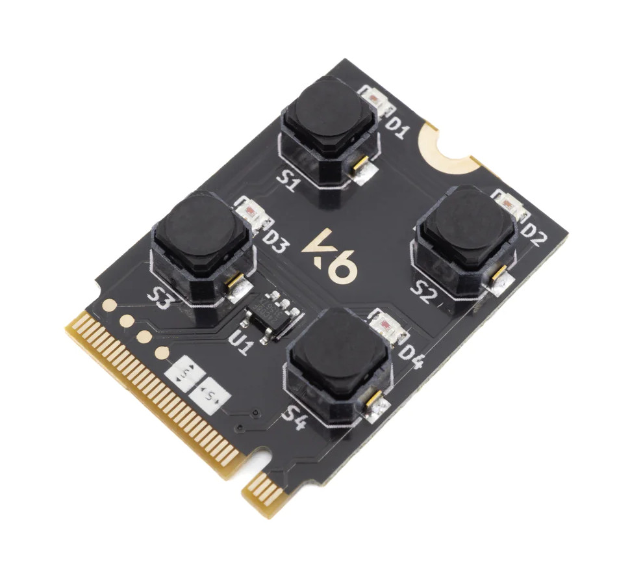
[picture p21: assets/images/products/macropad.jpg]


### QWIIC / VIK Adapter
_No ID assigned_

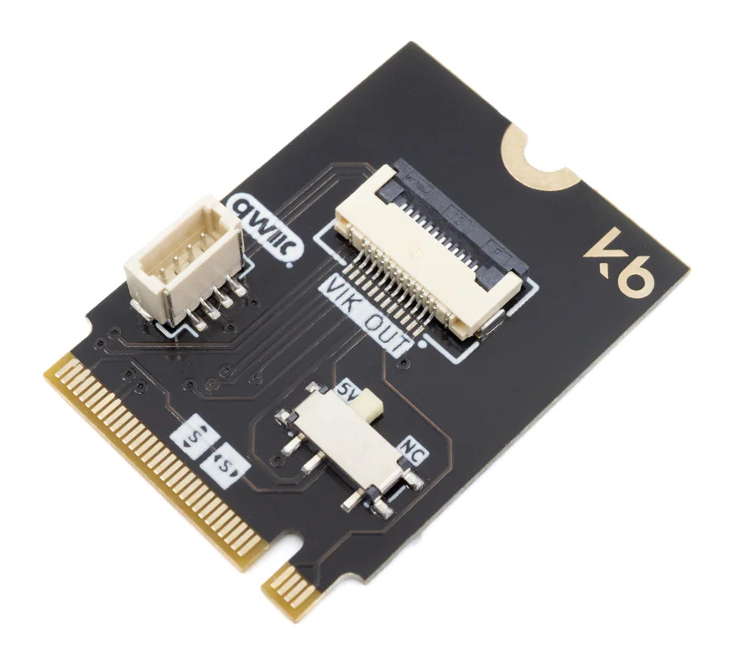
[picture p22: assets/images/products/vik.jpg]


### Protoboard
_No ID assigned_

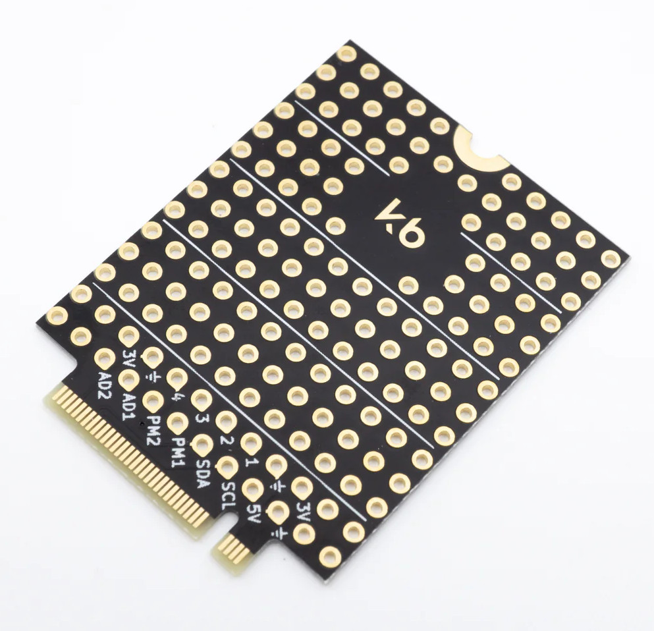
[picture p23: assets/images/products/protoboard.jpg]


Available in two sizes!

### Breakout
_No ID assigned_

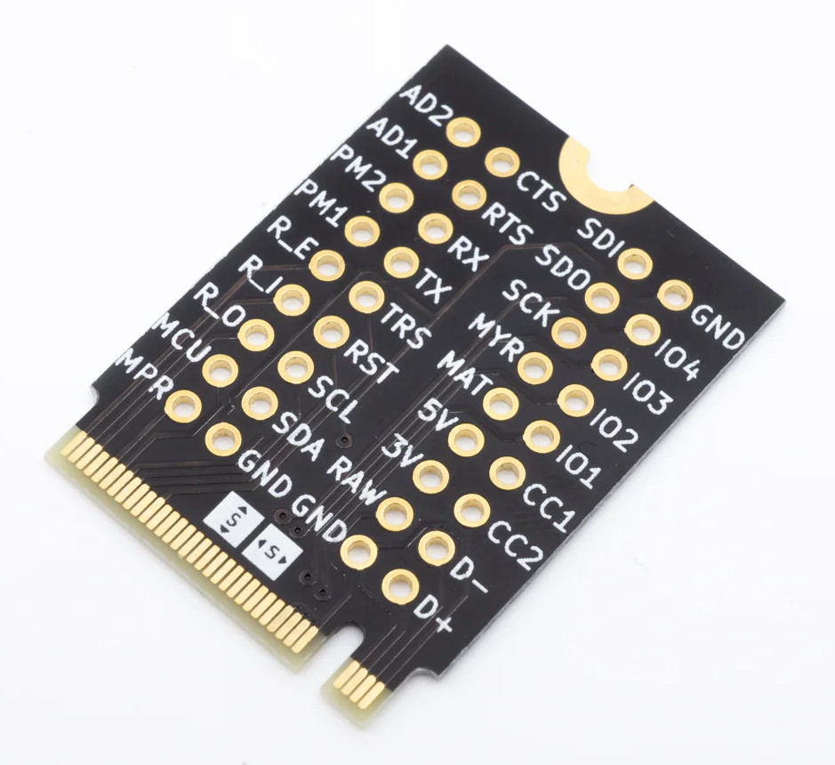
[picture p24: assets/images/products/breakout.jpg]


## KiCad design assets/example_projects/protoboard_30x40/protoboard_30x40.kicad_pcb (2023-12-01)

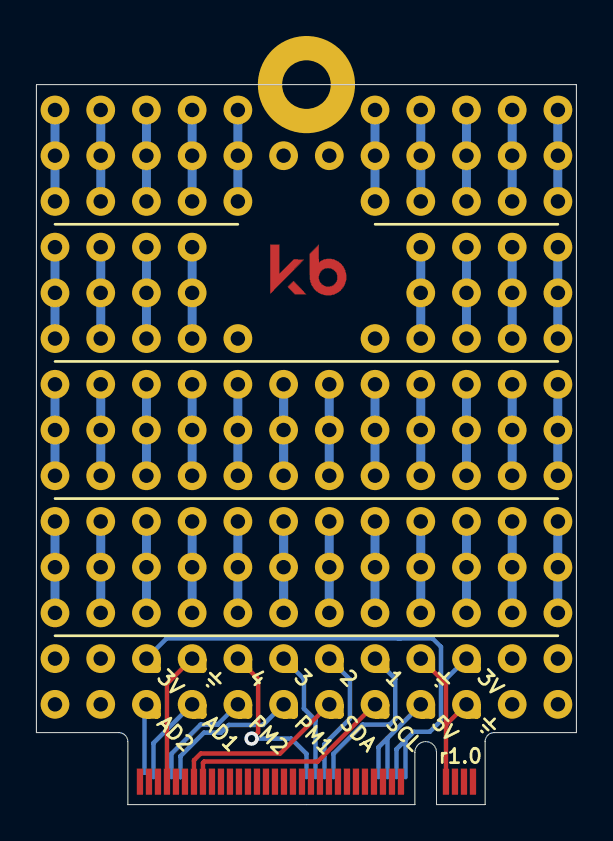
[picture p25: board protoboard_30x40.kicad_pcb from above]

Board: 2 copper layers, 30.0 x 40.0 mm, 17 parts (0 on the bottom side), 11 nets.

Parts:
J1: Myriad_Module_Connector; Myriad_Module_30x40mm
J2: AD1; ProtoPad
J3: AD2; ProtoPad
J4: PM1; ProtoPad
J5: PM2; ProtoPad
J6: 1; ProtoPad
J7: 2; ProtoPad
J8: 3; ProtoPad
J9: 4; ProtoPad
J10: SDA; ProtoPad
J11: SCL; ProtoPad
J12: 5V; ProtoPad
J13, J16: 3V; ProtoPad
J14, J15, J17: GND; ProtoPad

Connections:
+3V3: J1.16 (PWR_3V), J1.18 (PWR_3V), J13.1, J16.1
+5V: J1.20 (PWR_5V), J1.22 (PWR_5V), J12.1
GND: J1.1 (GND), J1.7 (GND), J1.40 (GND), J1.46 (GND), J1.54 (GND), J1.57 (GND), J1.64 (GND), J1.69 (GND), J1.70 (GND), J14.1, J15.1, J17.1
unnamed: J1.17 (PWR_RAW), J1.19 (PWR_RAW), J1.21 (PWR_RAW), J1.23 (PWR_RAW)
unnamed: J1.32 (GPIO_1), J6.1
unnamed: J1.34 (GPIO_2), J7.1
unnamed: J1.36 (GPIO_3), J8.1
unnamed: J1.38 (GPIO_4), J9.1
unnamed: J1.61 (I2C_SCL), J11.1
unnamed: J1.63 (I2C_SDA), J10.1
unnamed: J1.68 (PWM_2), J5.1

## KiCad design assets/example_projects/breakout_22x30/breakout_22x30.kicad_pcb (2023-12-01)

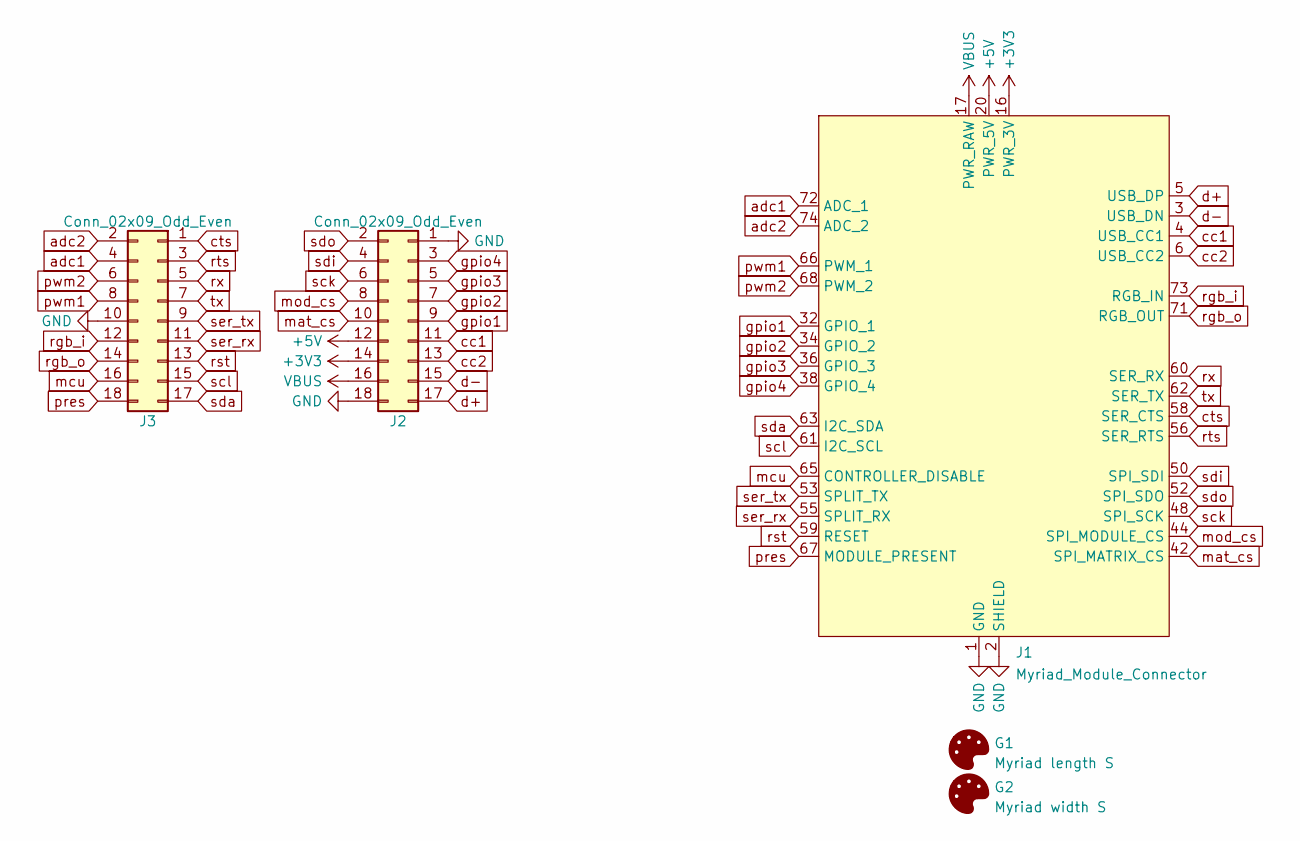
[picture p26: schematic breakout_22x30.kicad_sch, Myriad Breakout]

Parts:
G1: Myriad length S; Myriad_length-s
G2: Myriad width S; Myriad_width-s
J1: Myriad_Module_Connector; Myriad_Module_22x30mm
J2, J3: Conn_02x09_Odd_Even; PinSocket_2x09_P2.54mm_Vertical

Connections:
+3V3: J1.16 (PWR_3V), J1.18 (PWR_3V), J2.14
+5V: J1.20 (PWR_5V), J1.22 (PWR_5V), J2.12
GND: J1.1 (GND), J1.2 (SHIELD), J1.7 (GND), J1.40 (GND), J1.46 (GND), J1.54 (GND), J1.57 (GND), J1.64 (GND), J1.69 (GND), J1.70 (GND), J2.1, J2.18, J3.10
VBUS: J1.17 (PWR_RAW), J1.19 (PWR_RAW), J1.21 (PWR_RAW), J1.23 (PWR_RAW), J2.16
adc1: J1.72 (ADC_1), J3.4
adc2: J1.74 (ADC_2), J3.2
cc1: J1.4 (USB_CC1), J2.11
cc2: J1.6 (USB_CC2), J2.13
cts: J1.58 (SER_CTS), J3.1
d+: J1.5 (USB_DP), J2.17
d-: J1.3 (USB_DN), J2.15
gpio1: J1.32 (GPIO_1), J2.9
gpio2: J1.34 (GPIO_2), J2.7
gpio3: J1.36 (GPIO_3), J2.5
gpio4: J1.38 (GPIO_4), J2.3
mat_cs: J1.42 (SPI_MATRIX_CS), J2.10
mcu: J1.65 (CONTROLLER_DISABLE), J3.16
mod_cs: J1.44 (SPI_MODULE_CS), J2.8
pres: J1.67 (MODULE_PRESENT), J3.18
pwm1: J1.66 (PWM_1), J3.8
pwm2: J1.68 (PWM_2), J3.6
rgb_i: J1.73 (RGB_IN), J3.12
rgb_o: J1.71 (RGB_OUT), J3.14
rst: J1.59 (RESET), J3.13
rts: J1.56 (SER_RTS), J3.3
rx: J1.60 (SER_RX), J3.5
sck: J1.48 (SPI_SCK), J2.6
scl: J1.61 (I2C_SCL), J3.15
sda: J1.63 (I2C_SDA), J3.17
sdi: J1.50 (SPI_SDI), J2.4
sdo: J1.52 (SPI_SDO), J2.2
ser_rx: J1.55 (SPLIT_RX), J3.11
ser_tx: J1.53 (SPLIT_TX), J3.9
tx: J1.62 (SER_TX), J3.7

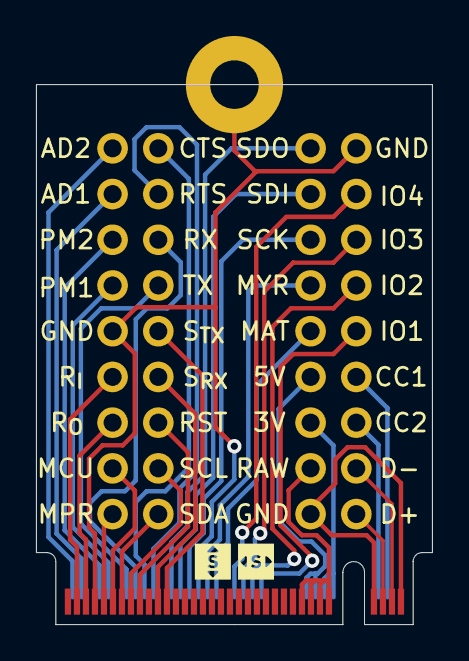
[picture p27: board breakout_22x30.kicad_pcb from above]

Board: 2 copper layers, 22.0 x 30.0 mm, 5 parts (0 on the bottom side), 34 nets.
